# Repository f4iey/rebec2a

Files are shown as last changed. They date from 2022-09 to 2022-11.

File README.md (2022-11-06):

# REBEC2A: Plateforme automobile Open Source
rebec2a wide logo

## Descriptif

**R**adio Controlled

**E**lectric

**B**ased

**E**xpermientation

**C**hassis for

**A**utomotive

**A**pplications

Le but de ce porjet est de convecoir d'abord, une plateforme minimale fonctionnelle de *modélisme* (donc la voiture, son châssis, son électronique, son firmware), ainsi que la commande à distance.

Le coeur du projet serait un microcontrôleur *ARM Cortex M7* assez puissant type *Teensy 4.1* ou *STM32F7*, afin de pouvoir connecter quelques capteurs; faire tourner des modèles de machine learning entraînés au préalable; implémenter de la vidéo FPV, de la conduite autonome, de l'évitement d'obstacles voire pourquoi pas s'amuser à faire un mode de dérapage autonome (inspiré de la MARTY, la [Delorean électrique](https://ddl.stanford.edu/marty/overview) autonome du Dynamic Design Lab de Stanford)

Un autre aspect intéressant est l'utilisation de matériel de *simulation de conduite* (que nous avons à disposition dans notre groupe), comme un pédalier et un volant pour une expérience de conduite plus ludique; où l'interface entre notre commande et ce matériel serait l'API du constructeur (Logitech ou Thrustmaster) par exemple.

Enfin, parce que nous apportons une importance particulière à redonner à la communauté qui nous a tant appris; nous trouvons important de fournir nos fichiers (notre code source, nos schémas electroniques et fichiers de CAD) [sous licence GPLv3](https://www.gnu.org/licenses/quick-guide-gplv3.fr.html).

Le tout pour aboutir au rêve du passionné du modélisme, d'électronique, de mécanique et de bricolage: une plateforme abordable, peu onéreuse, performante, facilement réplicable et abordable par des débutants et bien sur, facilement améliorable par les plus chevronnés, le tout dans un écosystème libre et ouvert.

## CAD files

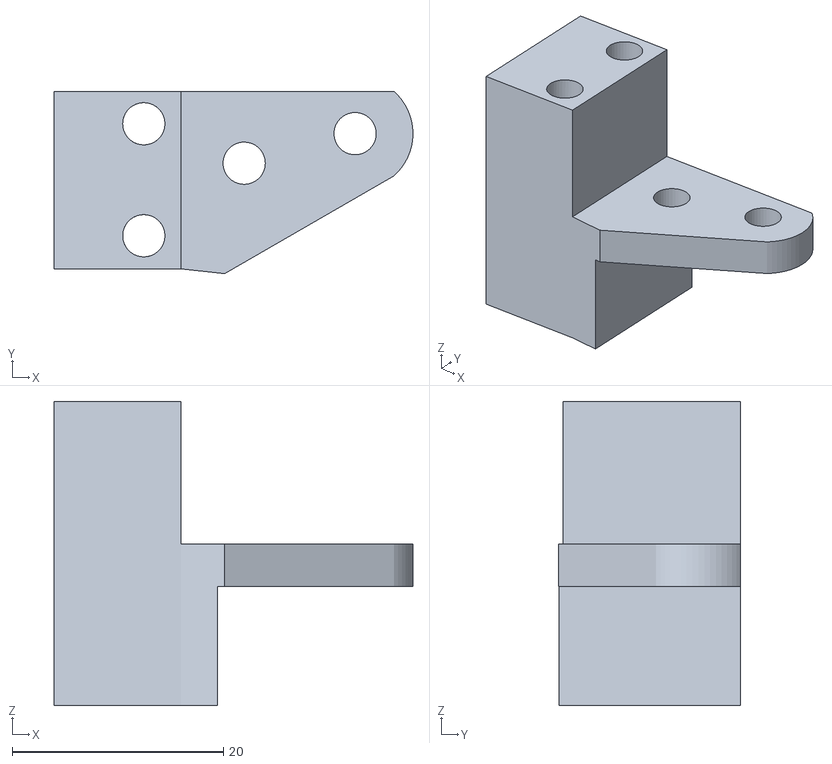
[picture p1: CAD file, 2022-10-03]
CAD FILES/0_V0/1_3D printing files/v3/RIGHT MOUNT.stl
34.0 x 17.2 x 28.8

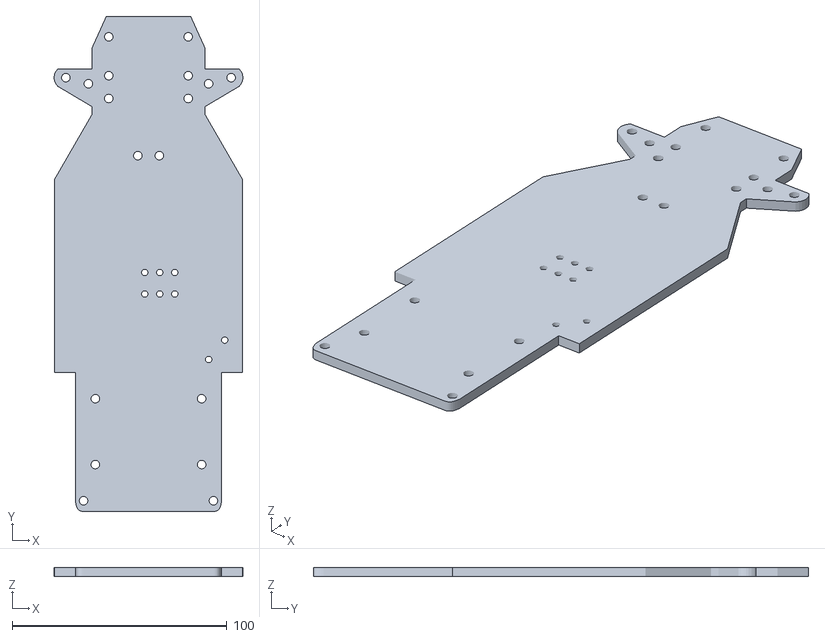
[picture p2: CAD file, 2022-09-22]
CAD FILES/0_V0/2_CNC machining files/CHASSIS.stl
87.9 x 230.5 x 4.00

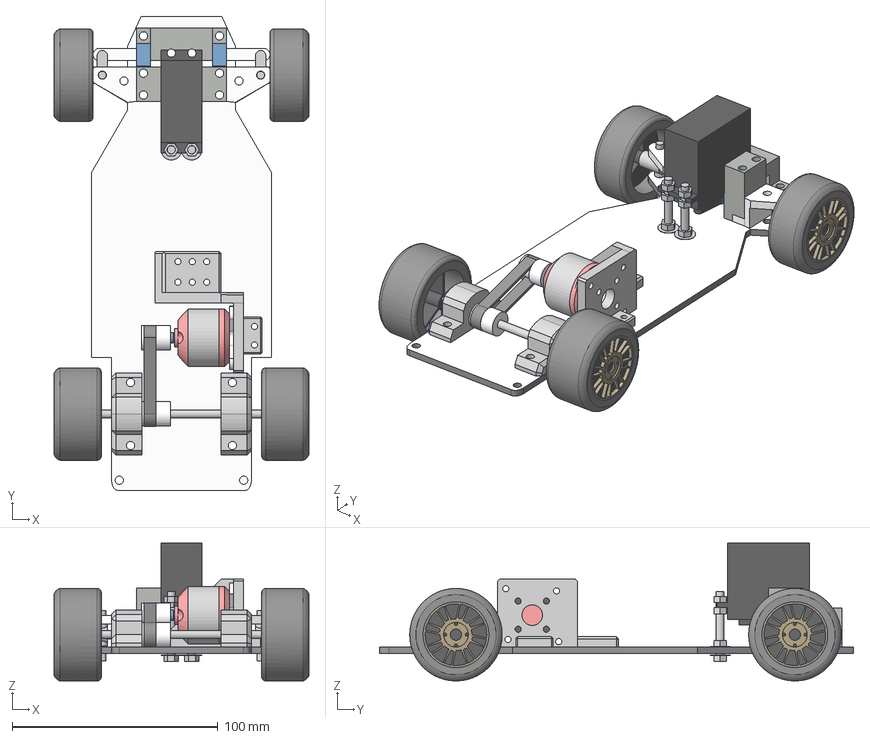
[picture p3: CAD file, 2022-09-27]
CAD FILES/0_V0/MODEL.step
124.0 x 230.5 x 67.1 mm

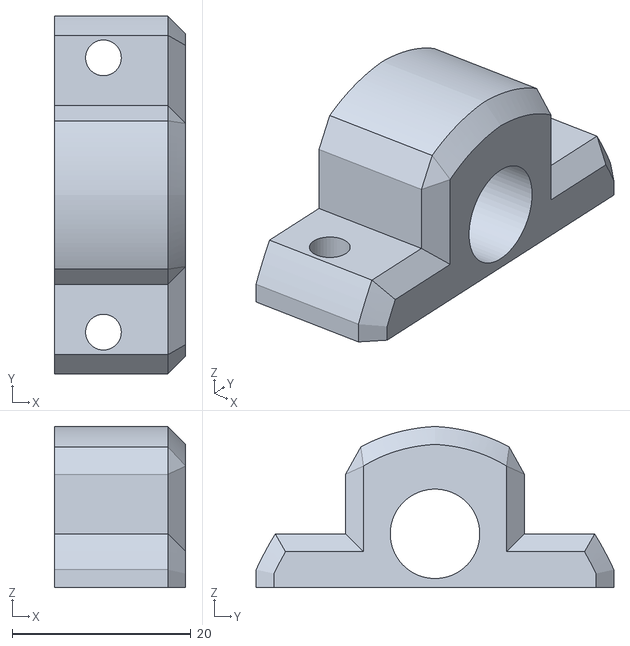
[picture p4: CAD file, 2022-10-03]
CAD FILES/1_V1/0_CAR/1_3D printing files/v3/bearing holder R.stl
14.7 x 40.0 x 18.0

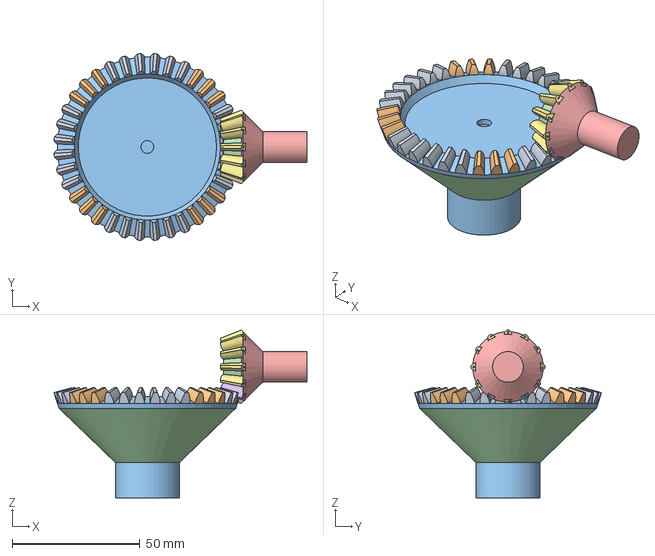
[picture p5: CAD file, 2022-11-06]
CAD FILES/1_V1/1_DIFF/AV-DIFF REBEC2A v4.step
98.9 x 73.0 x 65.6 mm
Spur Gear (36 teeth)
Spur Gear (12 teeth)

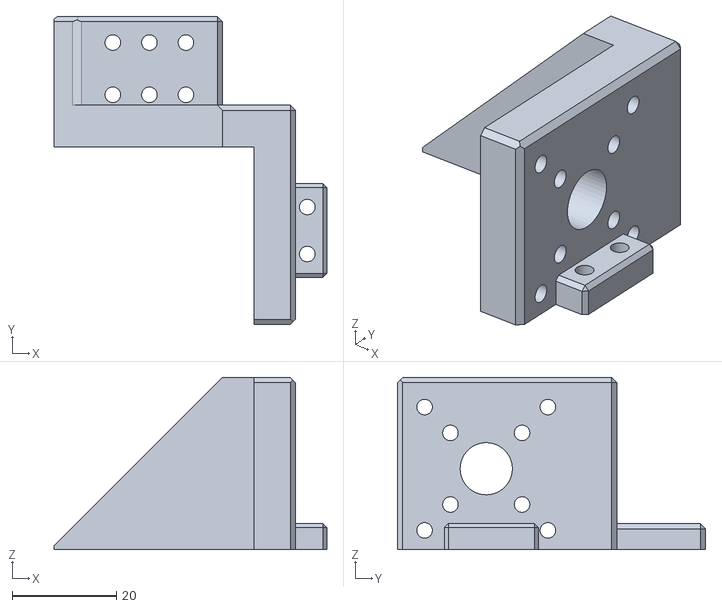
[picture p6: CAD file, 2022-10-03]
CAD FILES/1_V1/0_CAR/1_3D printing files/v3/BLDC CHASSIS MOUNT.stl
52.2 x 59.0 x 33.0

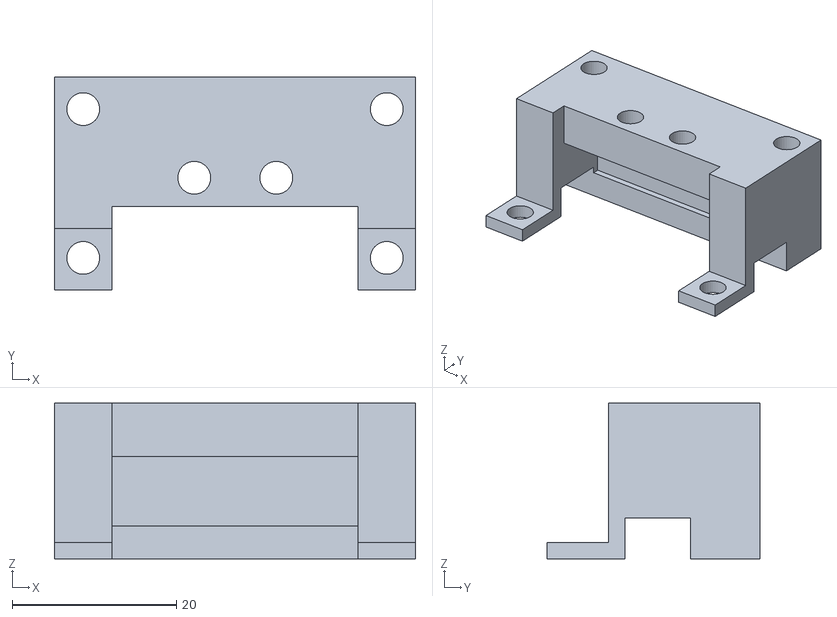
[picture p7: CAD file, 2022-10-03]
CAD FILES/0_V0/1_3D printing files/v3/FRONT MOUNT.stl
44.0 x 26.0 x 19.0

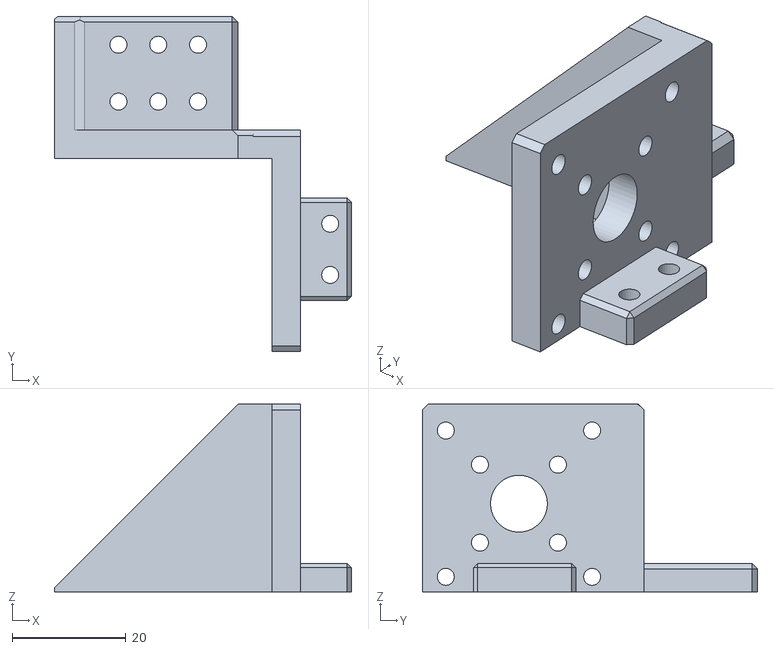
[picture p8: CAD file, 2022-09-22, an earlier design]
CAD FILES/0_V0/1_3D printing files/v0/stl/BLDC chassis mount (1).stl
52.2 x 59.0 x 33.0

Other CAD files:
CAD FILES/0_V0/1_3D printing files/v3/LEFT MOUNT.stl
CAD FILES/1_V1/0_CAR/1_3D printing files/v3/bearing holder L.stl
CAD FILES/1_V1/0_CAR/1_3D printing files/v3/LEFT MOUNT.stl
CAD FILES/0_V0/1_3D printing files/v3/bearing holder L.stl
CAD FILES/0_V0/1_3D printing files/v0/stl/3mm to 5mm shaft adapter (1).stl
CAD FILES/0_V0/1_3D printing files/v0/stl/Axle Mount top (1) (1).stl
CAD FILES/0_V0/1_3D printing files/v0/stl/Axle Mount top (2).stl
CAD FILES/0_V0/1_3D printing files/v0/stl/Bearing Holder (1) (1).stl
CAD FILES/0_V0/1_3D printing files/v0/stl/Bearing Holder (2).stl
CAD FILES/0_V0/1_3D printing files/v0/stl/Rack Holder L (1).stl
CAD FILES/0_V0/1_3D printing files/v0/stl/Rack Holder R (1).stl
CAD FILES/0_V0/1_3D printing files/v0/stl/Servo Front Clamp (1).stl
CAD FILES/0_V0/1_3D printing files/v0/stl/Servo Side Clamp (1) (1).stl
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

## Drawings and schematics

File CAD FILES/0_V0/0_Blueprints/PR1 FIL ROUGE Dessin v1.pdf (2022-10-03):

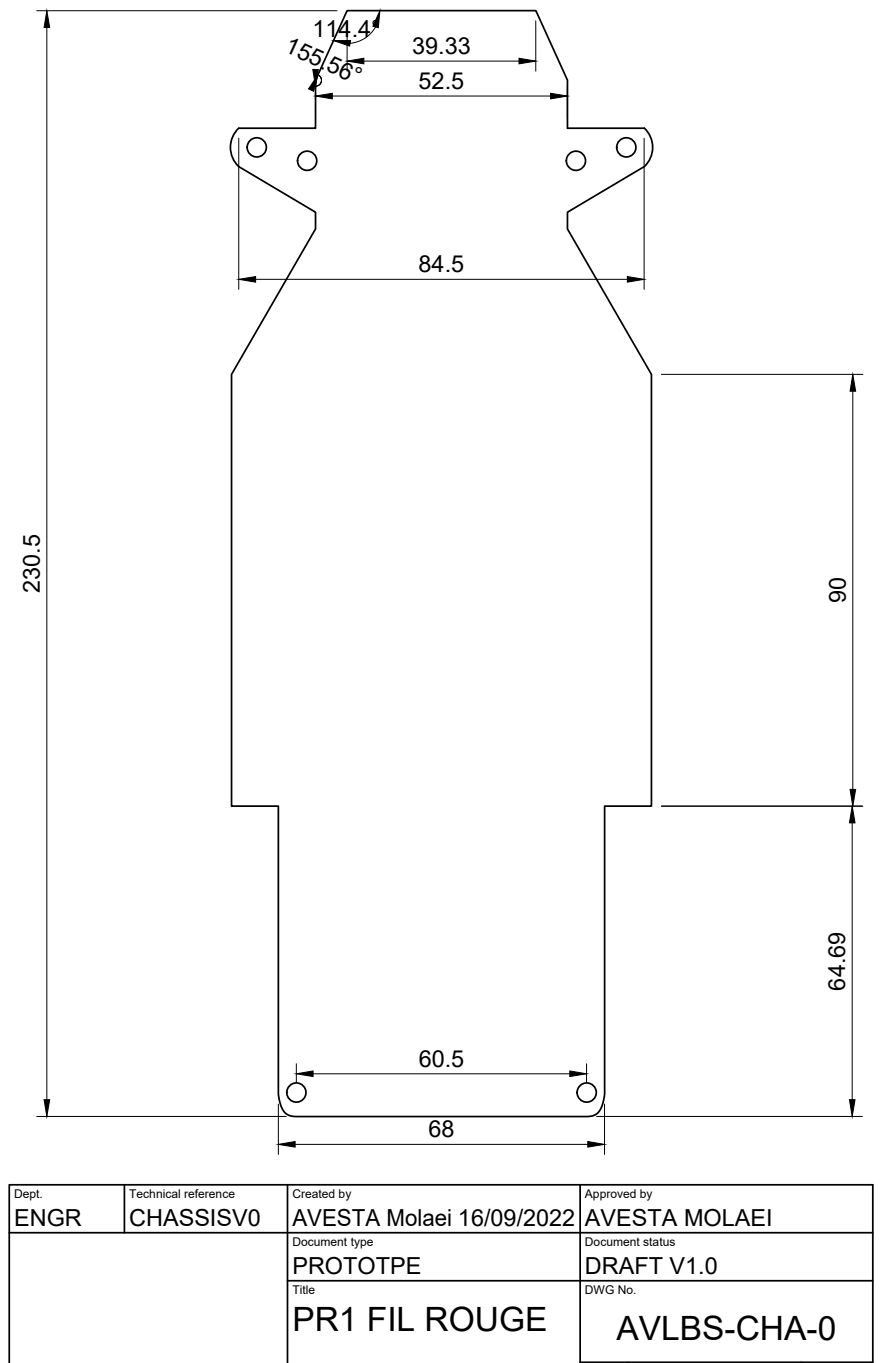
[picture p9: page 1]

Dept. ENGR | Technical reference CHASSISV0 | Created by AVESTA Molaei 16/09/2022 | Approved by AVESTA MOLAEI

Document type PROTOTPE | Document status DRAFT V1.0

Title PR1 FIL ROUGE | DWG No. AVLBS-CHA-0

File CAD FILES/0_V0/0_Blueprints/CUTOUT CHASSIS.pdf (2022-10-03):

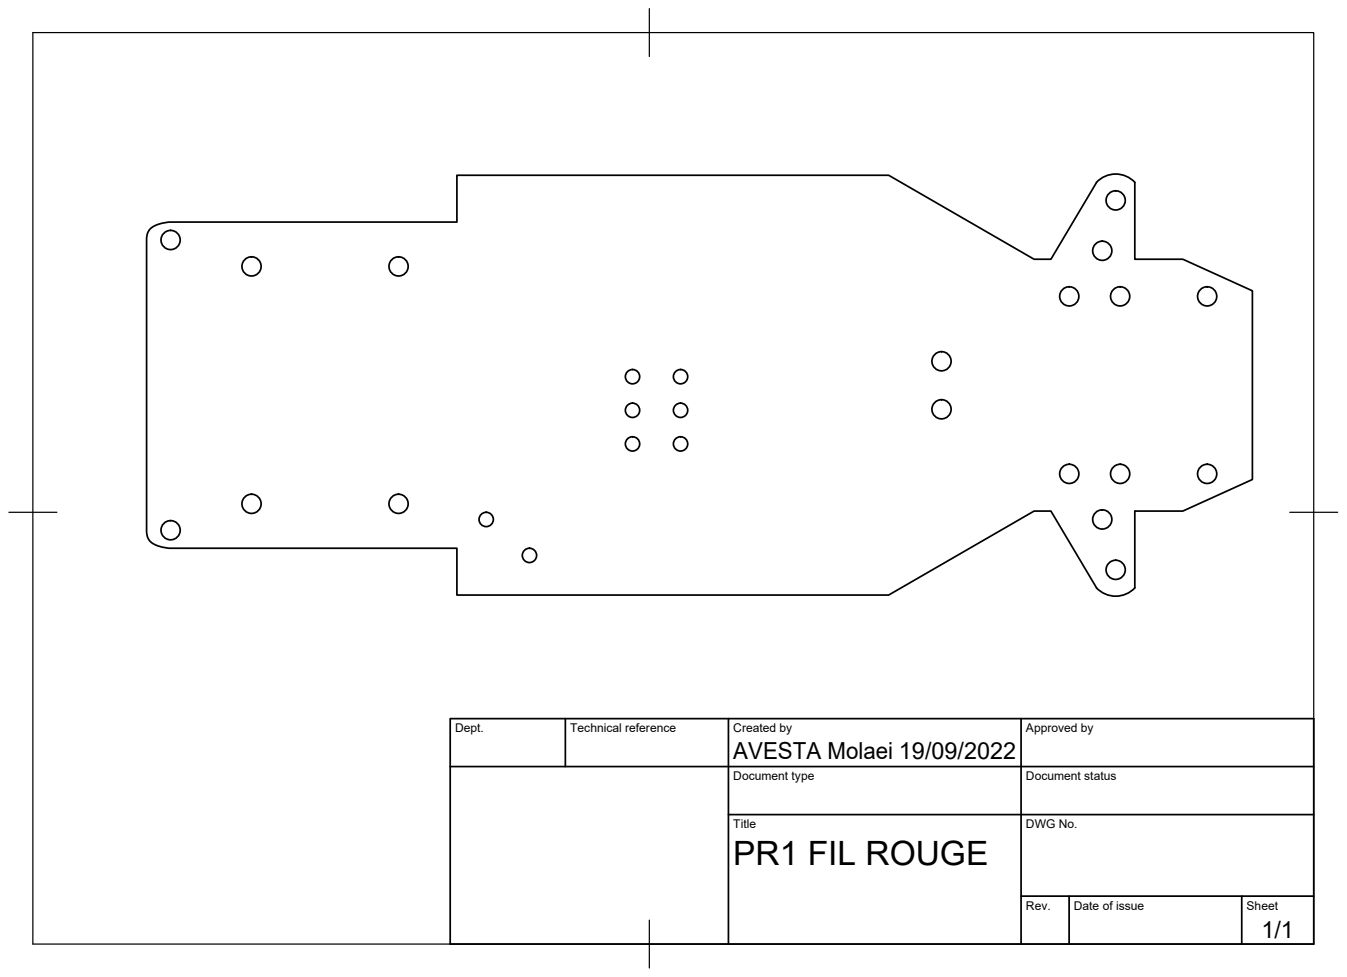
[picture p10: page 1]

Dept. | Technical reference | Created by AVESTA Molaei 19/09/2022 | Approved by

Document type | Document status

Title PR1 FIL ROUGE | DWG No.

Rev. | Date of issue | Sheet 1/1

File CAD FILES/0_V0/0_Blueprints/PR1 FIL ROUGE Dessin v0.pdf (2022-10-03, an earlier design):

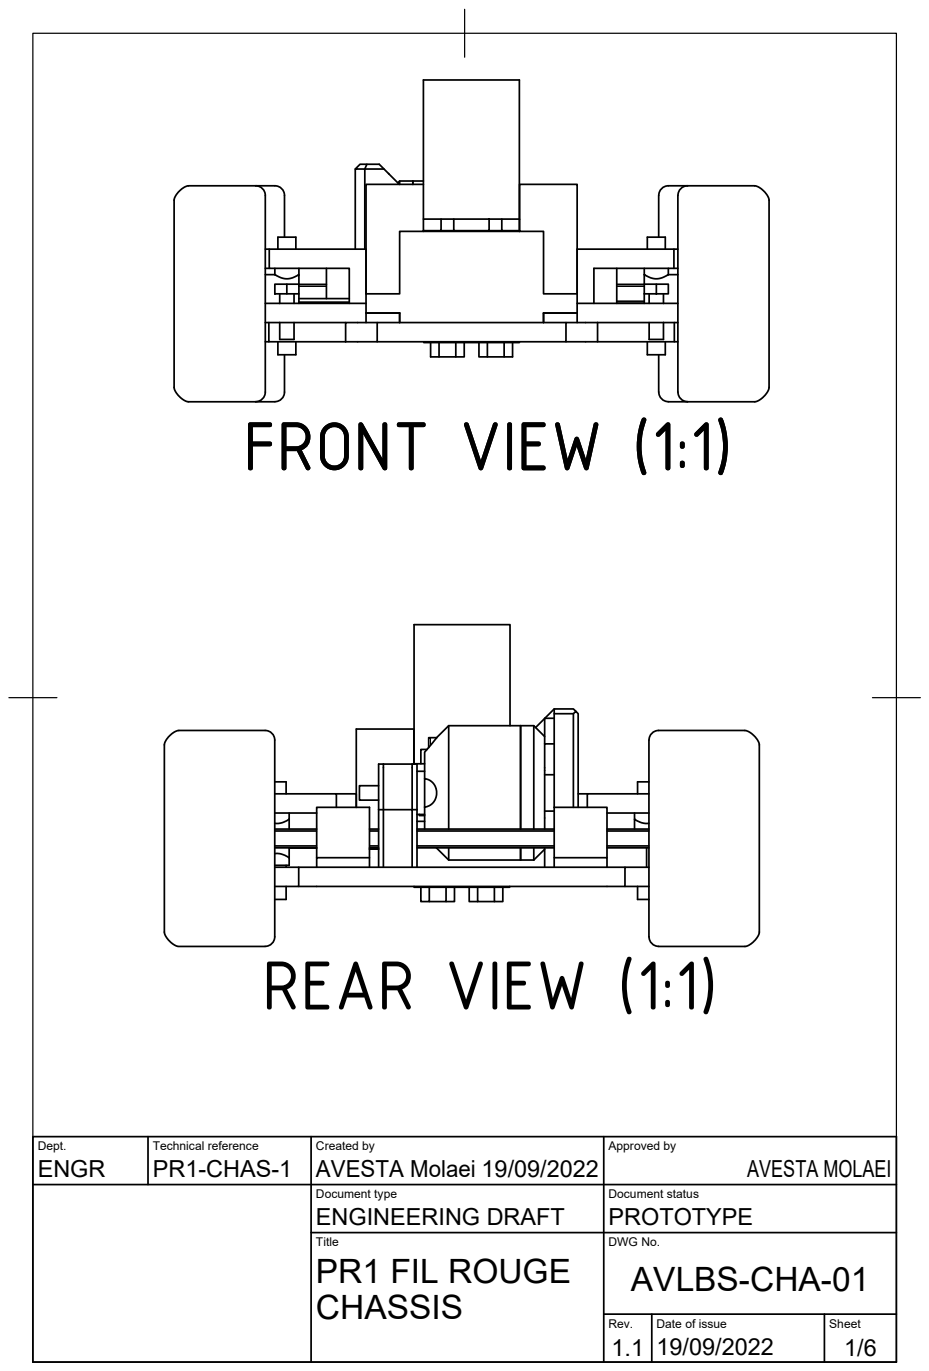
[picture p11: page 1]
FRONT VIEW (1:1); REAR VIEW (1:1)

Dept. ENGR | Technical reference PR1-CHAS-1 | Created by AVESTA Molaei 19/09/2022 | Approved by AVESTA MOLAEI

Document type ENGINEERING DRAFT | Document status PROTOTYPE

Title PR1 FIL ROUGE CHASSIS | DWG No. AVLBS-CHA-01

Rev. 1.1 | Date of issue 19/09/2022 | Sheet

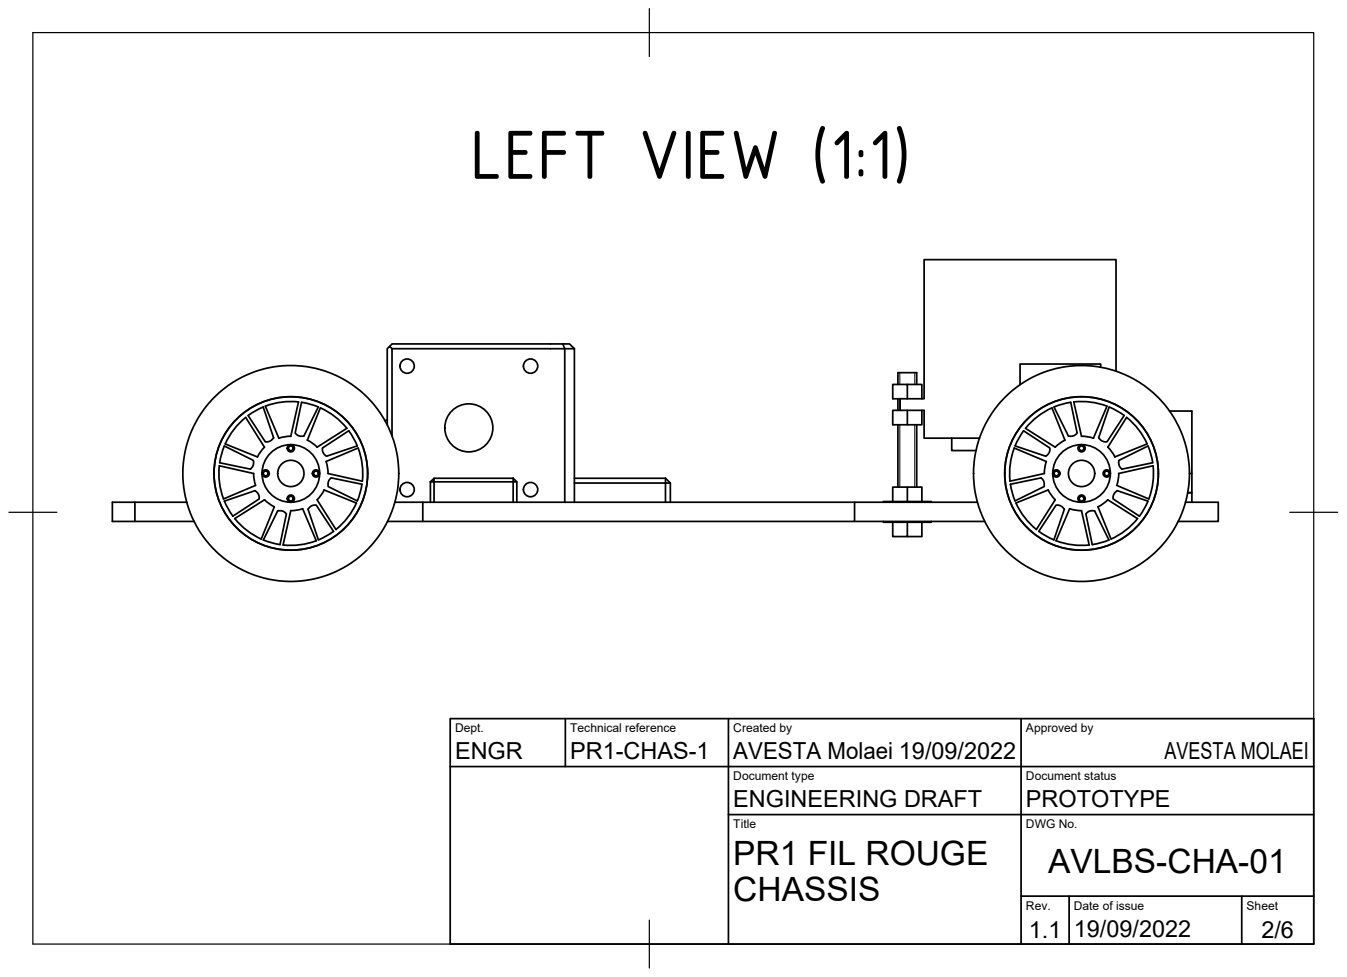
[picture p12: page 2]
LEFT VIEW (1:1)

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

Document type ENGINEERING DRAFT | Document status PROTOTYPE

Title PR1 FIL ROUGE CHASSIS | DWG No. AVLBS-CHA-01

Rev. | Date of issue | Sheet

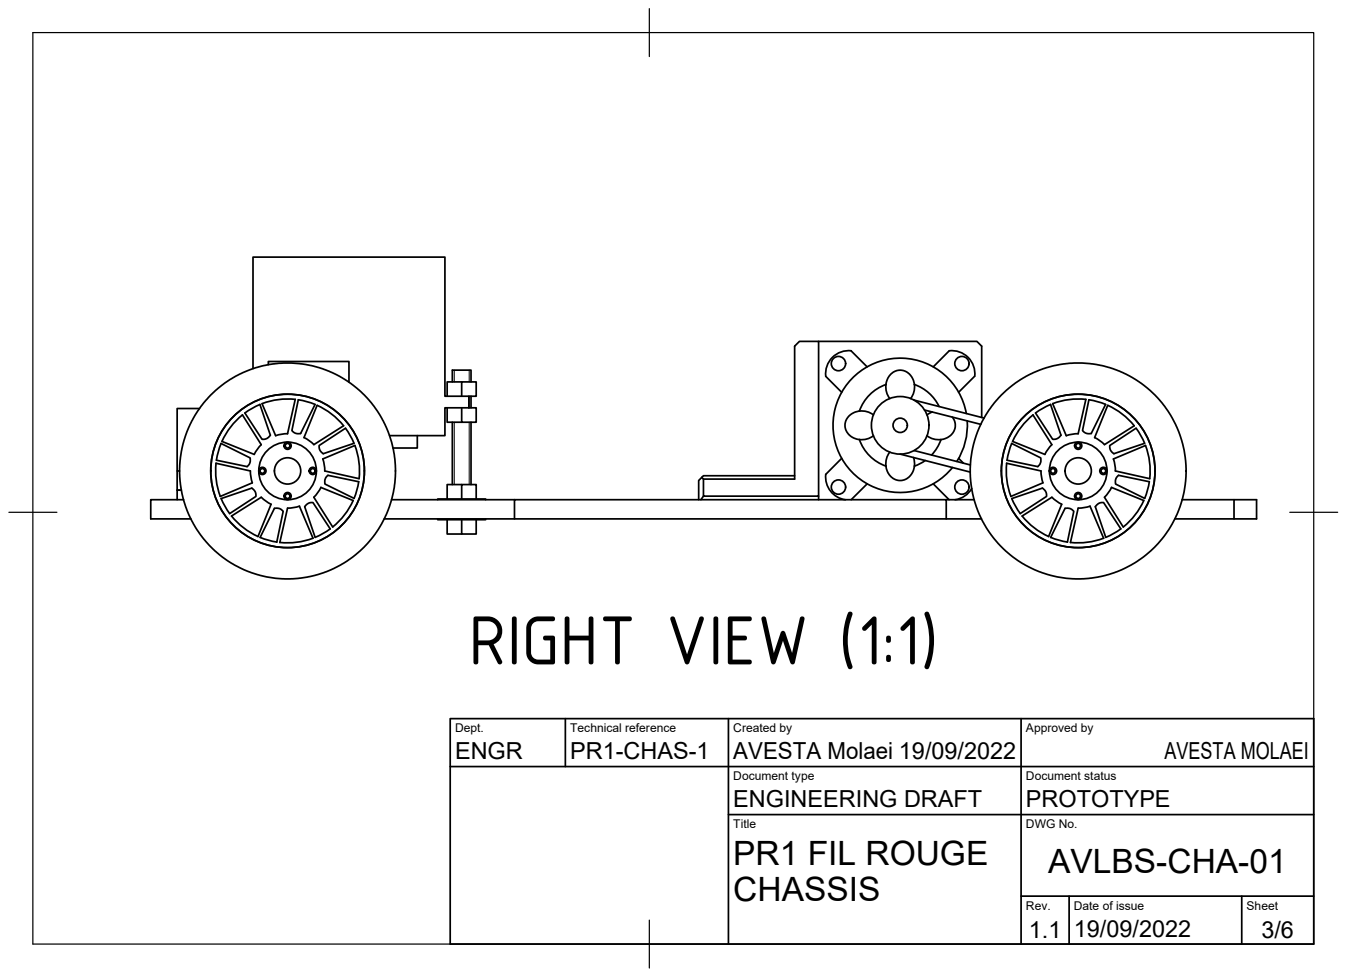
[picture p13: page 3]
RIGHT VIEW (1:1)

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

Document type ENGINEERING DRAFT | Document status PROTOTYPE

Title PR1 FIL ROUGE CHASSIS | DWG No. AVLBS-CHA-01

Rev. | Date of issue | Sheet

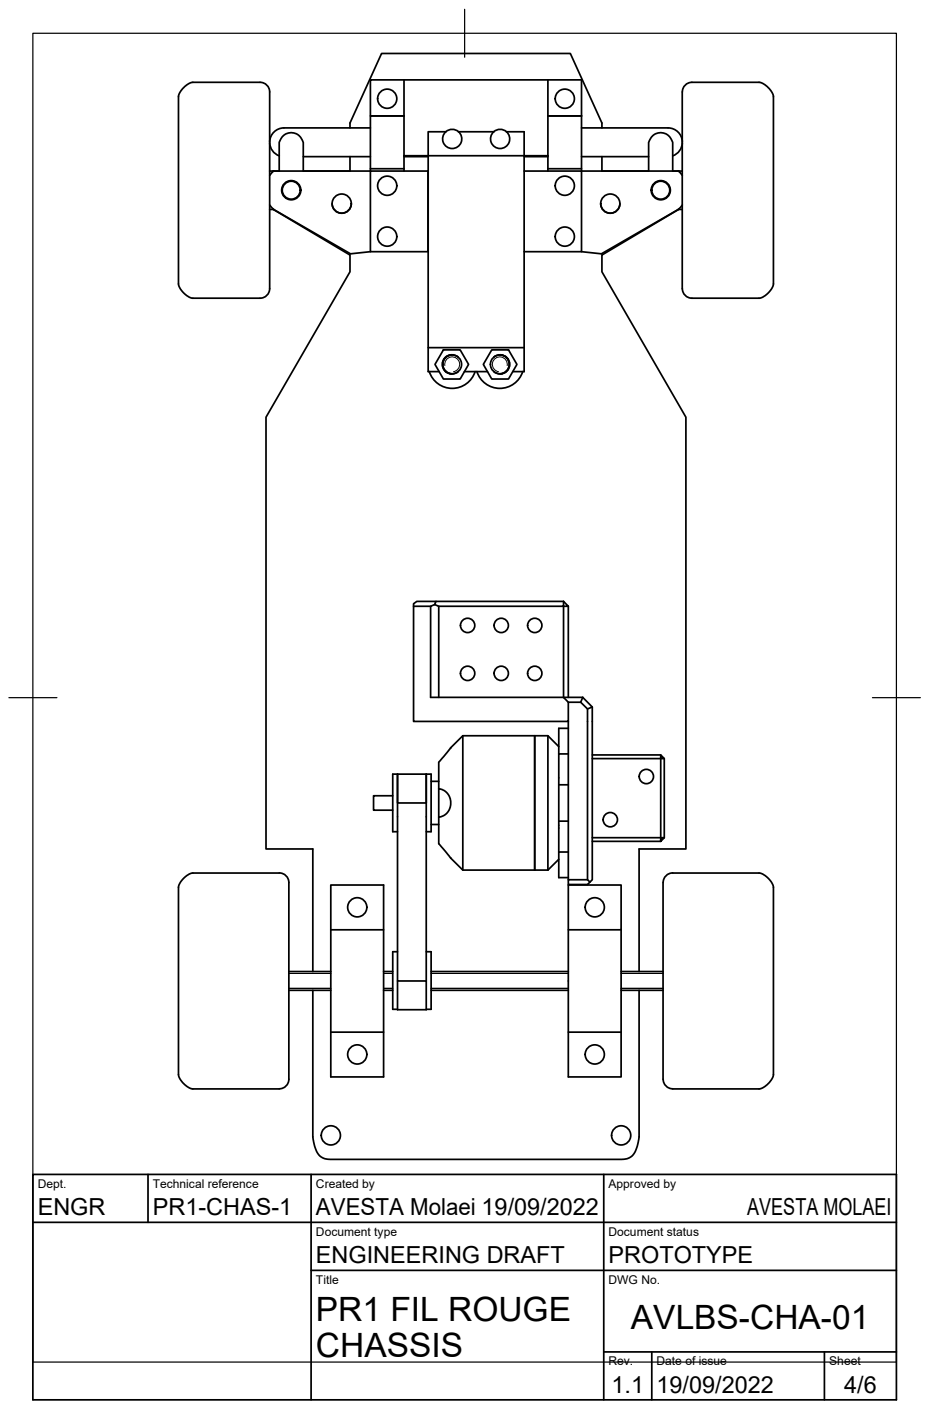
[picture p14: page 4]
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

Document type ENGINEERING DRAFT | Document status PROTOTYPE

Title PR1 FIL ROUGE | DWG No. AVLBS-CHA-01

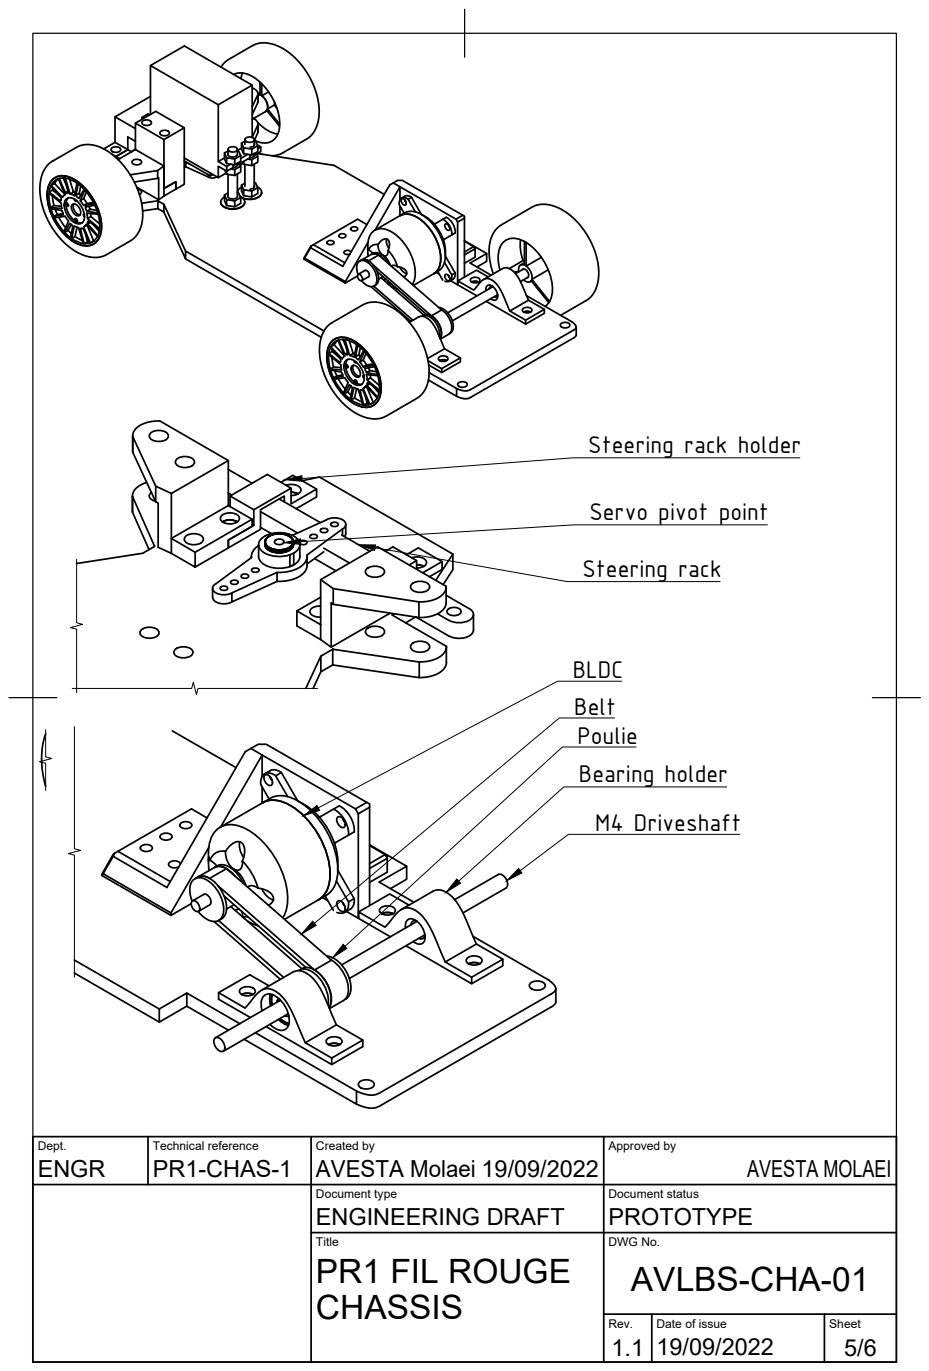
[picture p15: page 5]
Steering rack; Bearing holder; M4 Driveshaft

Steering rack holder

Servo pivot point

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

Document type ENGINEERING DRAFT | Document status PROTOTYPE

Title PR1 FIL ROUGE | DWG No. AVLBS-CHA-01

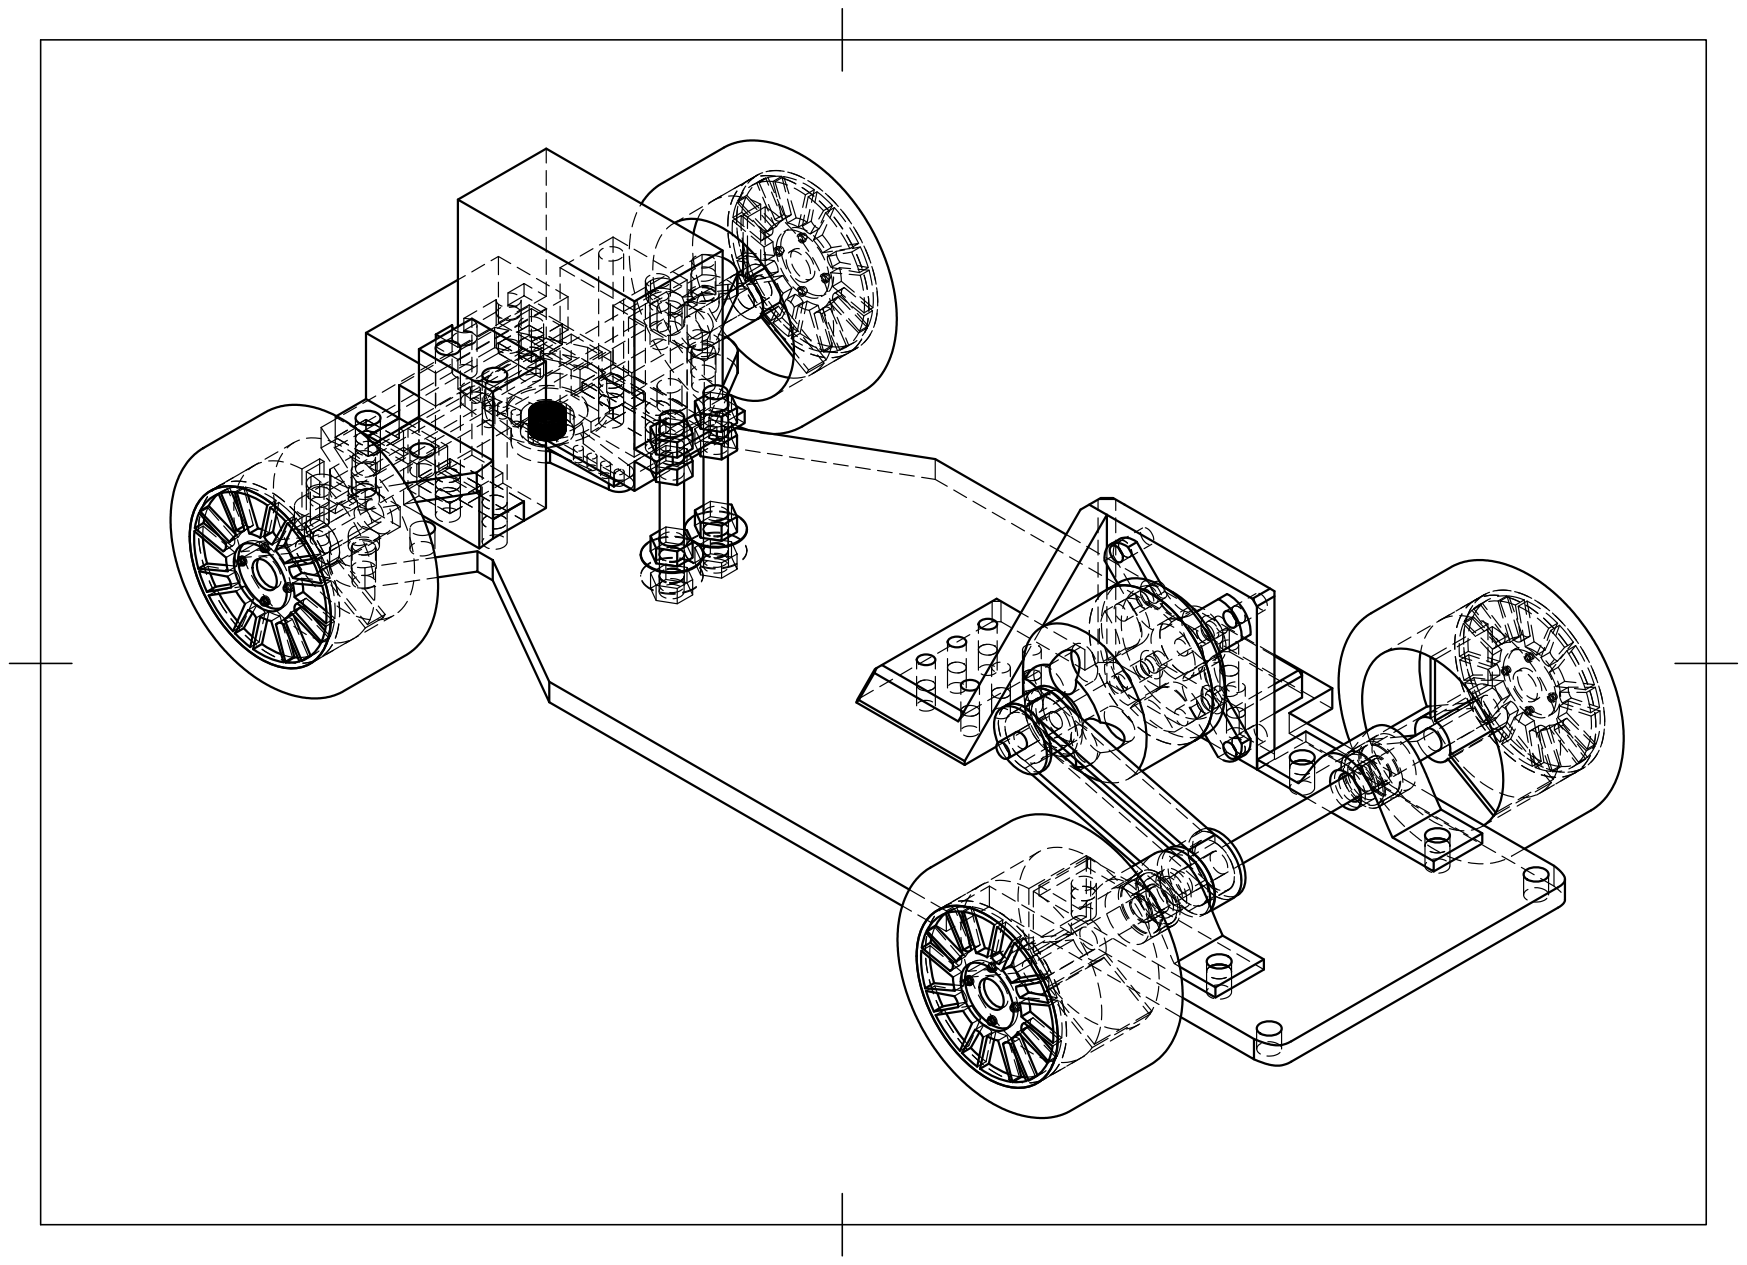
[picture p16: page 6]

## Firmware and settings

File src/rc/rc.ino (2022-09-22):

/*Arduino Uno TX FPV
 * using 2.4GHz
 * 2.4: Smaller antenna, multichannel so less interferences
 */
//PROTOS
void musique(int pitch);
void musiqueConnect(int pitch);
int mapExp(float valeur, float min, float max, float nMin, float nMax);
//end PROTOS 
#define C 523
#define G 784
#define GS 831
#define DS 622
#define F 698
#include <SPI.h>
#include <RF24.h>
RF24 tx (7, 8);
byte adresses[][6] = {"0"}; //fonction d'adressage: sorte de code couleur entre les modules
//initialisation générale
const int ledExpo = 9;
const int xPin = A0; //axe horizontal
const int yPin = A1; //vertical
const int gazPin = A4; //manette des gaz
const int rudPin = A5; //gouverne de direction
int x0, y0, x, y;
int buzz = 3; //pour affecter au digit 3
struct Package {
  int gazVal;
  //char aprs[60];
  int steerVal;
};
struct Package rc;

void setup() {
  pinMode(gazPin, INPUT); //la gestion des gaz se fait uniquement via tx
  //conditions initiales joystick
  pinMode(ledExpo, OUTPUT); //la led d'alerte expo
  digitalWrite(ledExpo, HIGH); /*la led expo est utilisée pour montrer que
  * le TX est en train de s'allumer */
  x0 = analogRead(xPin);
  y0 = analogRead(yPin);
  digitalWrite(ledExpo, LOW);
  //paramètres du TX
  digitalWrite(ledExpo, HIGH);
  SPI.begin();
  tx.begin();
  tx.setChannel(69); /*le module a 125 canaux (0-124)
  de 2400 à 2525 MHz
  */
  tx.setPALevel(RF24_PA_MAX); //puissance tx au max
  tx.setDataRate(RF24_250KBPS); //vitesse de transmission la plus lente pour plus de portée
  tx.openWritingPipe(adresses[0]); //on demande à l'appareil d'utiliser le code couleur souhaité
 // tx.openReadingPipe(1, adresses[0]); //on lui permet d'écouter
  digitalWrite(ledExpo, LOW); /*tout va bien l'utilisateur confirme que le TX
  est correctement allumé */
  musique(0); //c'est parti pour la SNCF!
  delay(1000);
  //tentavtive de connexion
  for(int i=0; i<3; i++) {
    //on fait clignoter la LED expo
    if(tx.available()) break;
    digitalWrite(ledExpo, HIGH);
    musiqueConnect(0);
    digitalWrite(ledExpo, LOW);
    if(tx.available()) break;
    delay(250);
  }
  //on émet un son pour dire qu'on est connecté
  tone(buzz, C);
  digitalWrite(ledExpo, HIGH);
  delay(500);
  noTone(buzz);
}

void loop() {
  //récupération données joystick: need cal?
  x = analogRead(xPin); /*- x0*/
  y = analogRead(yPin); /*- y0*/
  digitalWrite(ledExpo, LOW); //on allume la led expo
  //sinon on laisse les paramètres linéaires
  rc.steerVal = map(x, 0, 1023, 0, 180); //en degrés

  rc.gazVal = analogRead(gazPin); //récupération de la tension induite par la manette
  //écriture des données sur le port SPI
  tx.write(&rc, sizeof(rc)); //on envoie le paquet
  delay(15);
}

void musique(int pitch) {
  //fonction de musique de démarrage    
  tone(buzz, C+pitch);
  delay(500);
  tone(buzz, G+pitch);
  delay(500);
  tone(buzz, GS+pitch);
  delay(275);
  tone(buzz, DS+pitch);
  delay(500);
  noTone(buzz);
}

void musiqueConnect(int pitch) {
  //fonction de musique de connection    
  tone(buzz, DS+pitch);
  delay(125);
  tone(buzz, F+pitch);
  delay(125);
  tone(buzz, G+pitch);
  delay(250);
  noTone(buzz);
  delay(125);
}

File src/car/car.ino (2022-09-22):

/*  côté voiture
 *  to control motors & servos
 */
#include <SPI.h>
#include <RF24.h> 
#include <Servo.h>
RF24 rx (7, 8);
byte adresses[][6] = {"0"}; //meme code couleur que pour le tx
Servo axle; //on déclare l'aileron gauche
Servo ESC;

struct Package{
  int gazVal; //moteur
  //char aprs[60]; //trame APRSIS à envoyer
  int steerVal; //servo
};
struct Package rc;

/* ATTENTION:
 * la valeur gazVal doit bien être entre 0 et 1023!
 */

void setup() {
  axle.attach(9);
  ESC.attach(6);
  //réglages radio
  SPI.begin;
  rx.begin();
  rx.setChannel(69); //meme canal que rx
  rx.setPALevel(RF24_PA_MAX); //puissance max
  rx.setDataRate(RF24_250KBPS); //vitesse lente
  rx.openReadingPipe(1, adresses[0]); //on lui donne le code couleur à utiliser
  //rx.openWritingPipe(adresses[0]); //on lui permet d'ecrire
  //rx.startListening(); //c'est parti
  ESC.write(0); //on arme le brushless (procédure de démarrage)
  delay(15);
}

void loop() {
    //on met la LED en constant si on en a une
    rx.startListening();
    
   if(rx.available()) {
    while(rx.available()) {
      rx.read(&rc, sizeof(rc)); //on utilise les données recues pour les ailerons
      vitesseBrushless(rc.gazVal); //contrôleur
      axle.write(rc.steerVal);
      delay(15); //attend que le servo se mettent en place
      
    }
    //perte de connexion: on fait clignoter la LED à éclats
   }   
    //pas de télécommande à proximité: on fait clignoter la LED à occultations
   /* rx.stopListening();
    rx.write(&rc, sizeof(rc)); //on envoie un paquet test toutes les 750ms
    delay(750);
    //rx.startListening();*/
}

void vitesseBrushless(int gaz) {
    int commandeEsc = map(gaz, 0, 1023, 55, 135);
    ESC.write(commandeEsc);
}

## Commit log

2018-06-20 Problème de Timer résolu.
2018-07-03 problème allumage LED résolu (mode expo toujours hs)
2018-08-18 compatibilité ESC/moteur brushless ajoutée
2018-09-09 fonction rudder ajoutée
2020-01-21 rudder ajouté
2020-01-28 Changement des valeurs map
2020-01-28 Revoir les conditions pour tourner
2020-01-28 removed calibration
2020-01-28 Changement de la valeur médiane de 0 à 90
2020-01-29 Changement de scale du gaz
2020-01-30 Définition d'une "dead zone" de 5
2020-01-30 L'envoi des données est maintenant dans une structure Package; plus lisible qu'un tableau
2020-01-30 Mini opti + struct replaces array
    [TX24_FPV.ino]
2020-01-31 servo remap
2022-09-20 Ajout de LICENSE: replace MIT by GPL3
2022-09-20 Ajout de README.md
2022-09-22 added CAD FILES
    [3mm to 5mm shaft adapter (1).stl, Axle Mount top (1) (1).stl, Axle Mount top (2).stl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]
2022-09-27 what are you doing, step file???
    [PR1 FIL ROUGE v57.step]
2022-10-02 add chageur LiPo
2022-10-03 corrected a bunch of CAD mistakes, reorganized CAD files
    [3mm to 5mm shaft adapter (1).stl, Axle Mount top (1) (1).stl, Axle Mount top (2).stl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]
2022-11-06 reorganized CAD files, started revamp of chassis, started work on differential
    [3mm to 5mm shaft adapter (1).stl, AV-DIFF REBEC2A v4.f3d, AV-DIFF REBEC2A v4.step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]
